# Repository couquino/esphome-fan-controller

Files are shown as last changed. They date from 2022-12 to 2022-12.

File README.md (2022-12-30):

# ESPHome Fan Controller
This repo gives you all the keys to build a quiet thermostat-controlled fan for cooling any enclosure (media console, DIY server cabinet...)

The software is ESPHome and works well with Home Assistant. For hardware, I used an ESP8266 and Artic BioniX F140 140mm fans.

This project is based on [ESPHome Fan Controller](https://github.com/patrickcollins12/esphome-fan-controller)

## What do I need ?
To build my DIY server cabinet thermostat-controlled fans, I used:
- ESP8266 (Any board should be compatible)
- LM2596 Buck Converter - to convert 12v down to 3.3v
- 12v Power Adapter and 12v DC Female Jack
- 12v PWM 4-pin Computer Fan - I picked some [BioniX F140](https://www.arctic.de/en/BioniX-F140/ACFAN00096A) from Arctic but you can use any 12V PWM-controllable fan
- DHT 11 temperature and humidity sensor

I also hired someone to design a custom PCB with 3 fan headers and slots for each component, you can find it in /pcb folder and order it on JLCPCB for example. (Thanks shazmeter for letting me share your work !)

⚠️ This is the V1 version of the PCB, there are some modifications to be made in order to be perfect !
The DC Barrel input does not fit the power supply I had, and the FAN1, FAN2 and FAN3 pins are not thick enough to secure the FANs cables. ⚠️

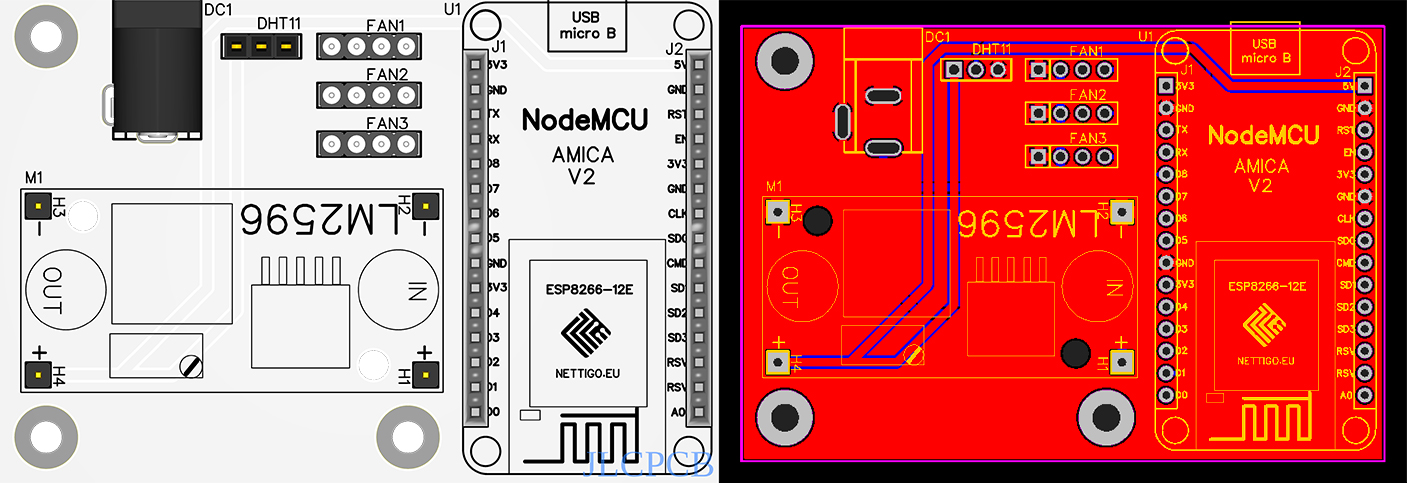
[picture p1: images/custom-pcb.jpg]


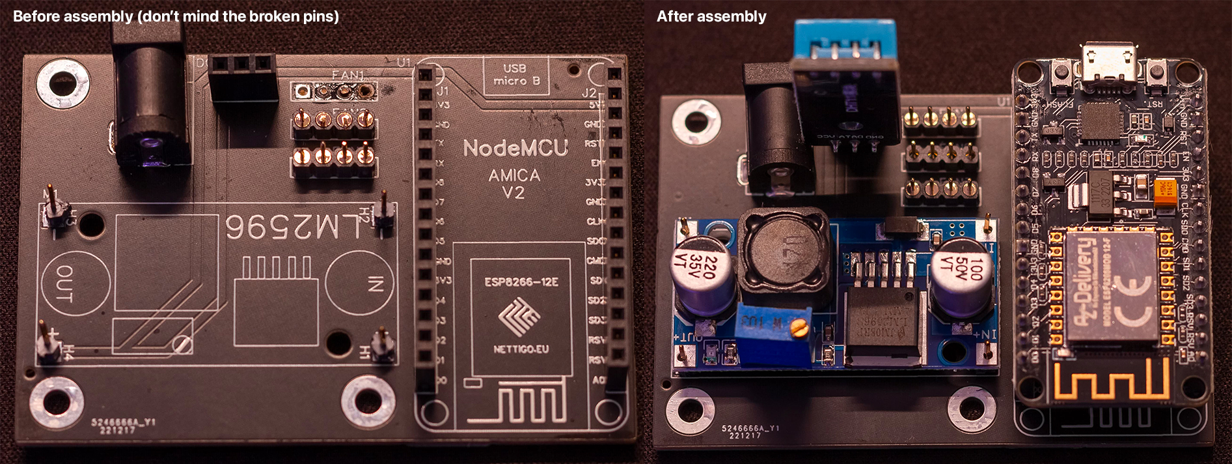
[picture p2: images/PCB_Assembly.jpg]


## Wiring Diagram
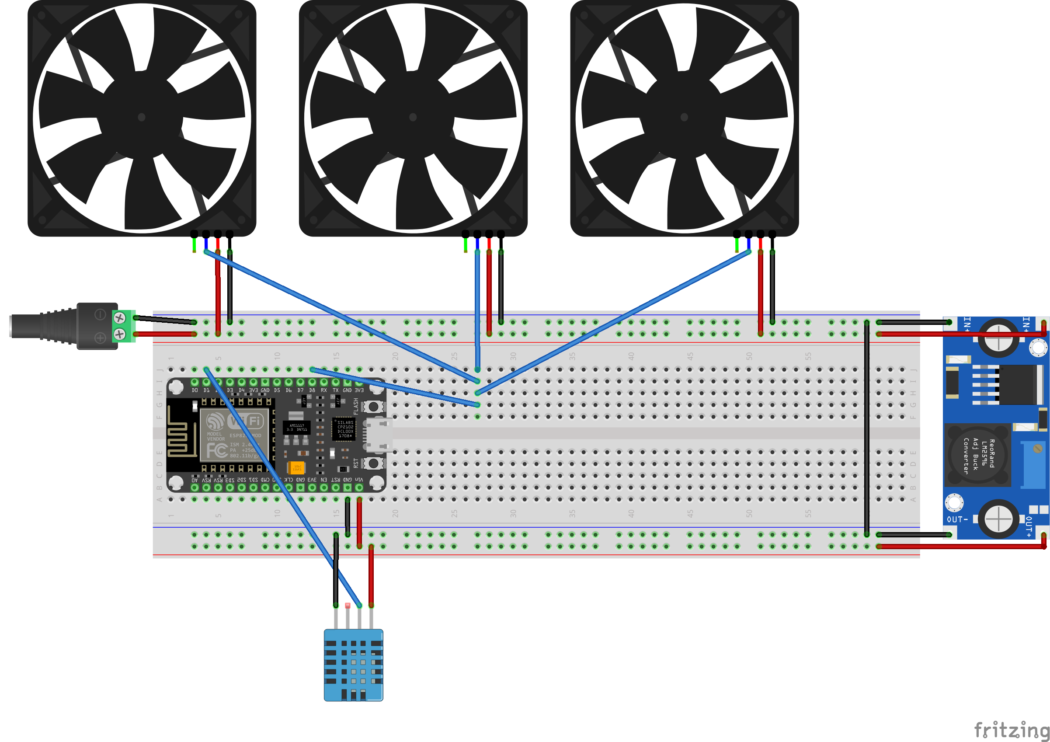
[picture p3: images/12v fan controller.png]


Some important notes:
- connect the fan PWM pin to a PWM GPIO
- turn the knob on the buck converter with a screwdriver to make it output exactly 3.3v. You'll need a multimeter to measure that output.
- ensure the 12v and 3.3v grounds are connected together.
- the unused pin on the fan is the "Tach" pin. This could tell you the RPM of the fan. We won't use this instead opting to measure the input voltage we're sending to the fan.
- you could easily skip the Buck converter and use two power sources 3.3v and 12v. 
- the fritzing diagram shows a 4-pin DHT-11, when in fact I have the simpler 3-pin version as shown in the parts list. The 4-pin version might need a pullup resistor, haven't tried it.

You can find the fritzing project in /fritzing-project folder

## Installing the software onto the ESP8266

### Get this repo
Clone this github repository.
From the command line cd into the directory

### Review the YAML and read the ESPHome docs.

Review the YAML file.

Ensure the pins are set correctly for the PWM Fan (D8) and the DHT-11 (D1).

Review the instructions for [the ESPHome Climate Thermostat](https://esphome.io/components/climate/index.html), [ESPHome PID Climate Thermostat](https://esphome.io/components/climate/pid.html) and the [DHT-11 sensor](https://esphome.io/components/sensor/dht.html).

Change the device name from ``console-fan`` to whatever seems appropriate. You might want to change the yaml filename as well.

Note that the DHT11 sensor is setup to average the last 15 readings. Each reading takes place every 1.5 seconds. Without this filter the PID controller reacts to every minor sensor movement. If you have a faster sensor like the BME260 you might need to tweak this filter.

```yaml
filters:
  - sliding_window_moving_average:
      window_size: 15
      send_every: 15
      send_first_at: 1
```

Also note that my fans have a max power of 80% applied to the fans to control the noise. You might want to remove this maximum.

```yaml
- platform: esp8266_pwm
    id: console_fan_speed
    pin: D8
    frequency: "25000 Hz" 
    min_power: 13%
    max_power: 80%
```

### Setup your wifi details

``mv secrets-sample.yaml secrets.yaml``

Edit your wifi credentials in secrets.yaml. The .gitignore will prevent you accidentally uploading your wifi credentials to github.

### Install ESPHome

[Install ESPHome](https://esphome.io/guides/installing_esphome.html) according to the instructions on the ESPHome website.

I prefer command-line on Mac:
``pip3 install esphome``

You could use the ESPHome that runs inside Home Assistant. 

### Install to ESP8266

Connect your ESP8266 via USB to your computer, then upload the Firmware to the ESP8266.

`` esphome run console-fan.yaml``

At this time if you've set the pins right, the sensor should be spitting out values and the PID can control the fan.

Success! 

```
% esphome logs console-fan.yaml
INFO Reading configuration console-fan.yaml...
INFO Starting log output from console-fan.local using esphome API
INFO Successfully connected to console-fan.local
...
[22:54:09][C][mdns:085]:   Hostname: console-fan
[22:54:09][C][homeassistant.text_sensor:023]: Homeassistant Text Sensor 'ha_kp'
[22:54:09][C][homeassistant.text_sensor:024]:   Entity ID: 'input_text.kp'
[22:54:10][C][homeassistant.text_sensor:023]: Homeassistant Text Sensor 'ha_ki'
[22:54:10][C][homeassistant.text_sensor:024]:   Entity ID: 'input_text.ki'
[22:54:10][C][homeassistant.text_sensor:023]: Homeassistant Text Sensor 'ha_kd'
[22:54:10][C][homeassistant.text_sensor:024]:   Entity ID: 'input_text.kd'
[22:54:10][D][dht:048]: Got Temperature=30.0°C Humidity=38.0%
[22:54:10][D][sensor:113]: 'Humidity': Sending state 38.00000 % with 0 decimals of accuracy
[22:54:11][D][dht:048]: Got Temperature=30.0°C Humidity=38.0%
[22:54:11][D][sensor:113]: 'Humidity': Sending state 38.00000 % with 0 decimals of accuracy
[22:54:12][D][dht:048]: Got Temperature=30.0°C Humidity=38.0%
[22:54:12][D][sensor:113]: 'Humidity': Sending state 38.00000 % with 0 decimals of accuracy
```

## Setup Home Assistant

If the above steps worked correctly, the device will be auto-discovered by Home Assistant. You will need to add the device.

Multiple sensors and switches are exposed by the ESPHome software.

You also need to setup the dashboard. I'll explain those two steps below.

## Setting up the Home Assistant Dashboard

dashboard

Here is my full dashboard in Home Assistant.

Let's go through them section by section.

### The Primary Controls



By clicking the thermostat you can turn on/off the thermostat and fan and adjust the target temperature which will be persisted to flash on the ESP8266.

```yaml
type: entities
title: Console Fan
entities:
  - entity: sensor.fan_speed_pwm_voltage
  - entity: climate.console_fan_thermostat
  - entity: sensor.contact_sensor_1_temperature
    name: Room Temperature
  - entity: sensor.openweathermap_temperature
    name: Outside temperature
  - entity: number.console_fan_kp
  - entity: number.console_fan_ki
  - entity: number.console_fan_kd
  ```

- The ``Fan Speed (PWM Voltage)`` is the % of voltage being sent out via PWM to the fan controller. At 100% it will be sending 12v, at 50% it will be sending 6v.

- The ``Console Fan Thermostat`` is a controllable thermostat, by clicking it you can alter the target temperature and turn the fan on/off.

- The Room and Outside temperatures are from other sensors in my house for reference.

- The ``kp, ki and kd`` inputs are exposed from the device. Your ESP8266 will be automatically receiving changes to these values to control the behavior of the PID controller. While you could tune these from the config.yaml it requires a compile, upload and reboot cycle each time. This is inconvenient and best to tweak in real-time. We want to expose these 3 parameters to a Home Assistant dashboard.

### The Graphs



Add the fan speed and the thermostat to two separate graphs. I've also added my room temperature from a separate device for comparison.

```yaml
type: vertical-stack
title: 3 hr
cards:
  - type: history-graph
    entities:
      - entity: sensor.fan_speed_pwm_voltage
    hours_to_show: 3
    refresh_interval: 0
  - type: history-graph
    entities:
      - entity: climate.console_fan_thermostat
        name: ' '
      - entity: sensor.contact_sensor_1_temperature
        name: room
    hours_to_show: 3
    refresh_interval: 0
```

### Helpful Details - More Sensors and Switches



This Lovelace YAML exposes various sensors and switches from the ESP8266.

```yaml
type: entities
entities:
  - entity: sensor.console_fan_ip_address
  - entity: sensor.console_fan_wifi_strength
  - entity: sensor.console_fan_uptime
  - entity: sensor.humidity
    name: console fan humidity
  - entity: switch.console_fan_autotune
  - entity: switch.console_fan_ESP8266_restart
```

- ``console_fan_autotune`` is a switch which starts the [PID tuning](https://esphome.io/components/climate/pid.html#autotuning) process. I ended up abandoning this approach and manually tuning the PID.

- ``console_fan_ESP8266_restart`` restarts the ESP8266 remotely.

## Configuring the PID Parameters

The thermostat is controlled using a standard Process Control system called a PID. 

In our system the goal of the PID control is to set the fan voltage (speed) to bring the temperature measured by the sensor to a target temperature (30degC).

Search the internet and you'll find many resources for setting up a PID Controller. There are a lot of resources for fast response systems like cruise control systems but not many for dealing with slow response cooling systems like this one.

The [ESPHome PID Climate](https://esphome.io/components/climate/pid.html) system that we're using here has some resources to explain how to tune the parameters. However, its autotune system didn't spit out useful results for me and I will explain how to manually get the right parameters. Your system will be different to mine and so your parameters will need to be slightly different. For instance, your cabinet will be a different size, I have two fans, you may only have one, etc.

There are only two parameters you will need to adjust: the kp and ki parameters. The kd parameter is not useful for us.

In my system the goal of tuning was to minimise aggressive changes to the fan (my wife complained she could hear the fan turning on and off). I don't mind the system drifting up to 2degC away from the target temporarily while it slowly reacts. A 7% drift (2degC/30degC) on some control systems could blow up a Nuclear plant or cause a Cruise Control system to crash into another car. But in our system a 7% short temperature drift is a fine tradeoff for quiet fans.

### Setting the kp (gain) parameter - how aggressively to cool?

KP is the main Gain. How aggressively will the fan respond to a small change in temperarature? Do you want the fan to go to 100% power in response to a 0.1degC change in temperature? In general my goal was to have the fan at 50% in response to a 1degC change in temperature, thus could normally stave off any further temperature rises, but if it the temperature did keep rising the fan will then climb to 100% power.

Using lower gain (0.1) (my preferred setting):
 - takes longer to cool down
 - is more likely to under react to fast temperature changes.
 - 2deg sharp spikes can occur before the system reacts
 - It can takes up to 10 minutes to fully close a 0.5degC gap.
 - but, it is much less likely to oscillate around the target temperature and cause the fan to turn on and off constantly.

Using higher gain (1.0):
 - responds quickly to changes in temperature
 - but, is more likely to oscillate and make the fan swing from 0% to 100% and back again as it tries to control the temperature. This means you can hear the fan trying to adjust.

### Setting the ki parameter - how long to adjust an offset?

``ki: 0.0009``

The ki parameter adjusts for temperature offset. Try setting ki to 0. Set your system initially with kp=0.1, ki=0 and kd=0. You'll find that the system operates with a constant delta/offset to the target temperature. The ki parameter adjusts for this.

1/ki is the seconds it should attempt to correct an offset. So 0.03 will adjust in 30seconds. 0.0009 will close a small temperature delta in 20 minutes. See a good description here https://blog.opticontrols.com/archives/344

Higher numbers like 0.03 will respond much quicker, but it also will cause a lot of noise and oscillation in the fan speed.

### Setting the kd parameter - predicting a change

The kd (D in PID) is meant to pre-react and backoff early. Small parameters can help overshoot but does create some fan noise and oscillation. The interwebs says that most (70%) of process controllers don't use the D and just a PI controller.

### Tell me
I'm keen to hear what PID parameters works for your fan.

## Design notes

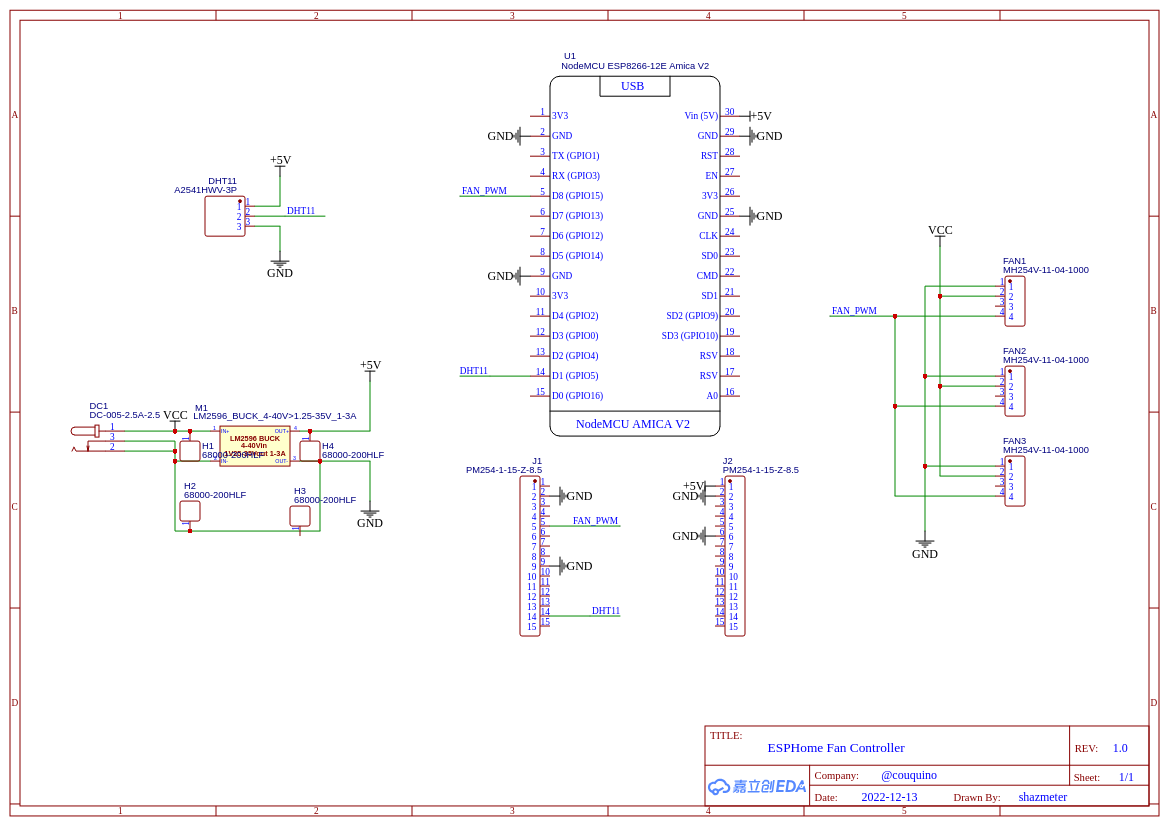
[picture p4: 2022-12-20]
images/custom-pcb-schema.png

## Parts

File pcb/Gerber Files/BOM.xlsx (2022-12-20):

Name | Designator | Footprint | Quantity | Manufacturer Part | Manufacturer | Supplier | Supplier Part | Price
DC-005-2.5A-2.5 | DC1 | CONN-TH_DC-005-2.5A-2.0 | 1 | DC-005-2.5A-2.5 | XKB Enterprise | LCSC | C319098 | 0.014
A2541HWV-3P | DHT11 | HDR-TH_3P-P2.54-V-F-1 | 1 | A2541HWV-3P | CJT(长江连接器) | LCSC | C225500 | 0.011
MH254V-11-04-1000 | FAN1,FAN2,FAN3 | HDR-TH_4P-P2.54-V-M-3 | 3 | MH254V-11-04-1000 | XFCN(兴飞) | LCSC | C509261 | 0.015
68000-200HLF | H1,H2,H3,H4 | HDR-TH_1P-P2.54-V-M | 4 | 68000-200HLF | Amphenol | LCSC | C213187 | 0.008
PM254-1-15-Z-8.5 | J1,J2 | HDR-TH_15P-P2.54-V-F | 2 | PM254-1-15-Z-8.5 | HCTL(华灿天禄) | LCSC | C2897378 | 0.036

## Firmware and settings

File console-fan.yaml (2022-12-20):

substitutions:
  friendly_name: Console Fan

esphome:
  name: console-fan

  # on_boot:
  #   priority: -100
  #   then: 
  #     lambda: |-
  #       // delay(10000);
  #       ESP_LOGI("main", "!!!!!! kp from boot %f", id("console_fan_kp") );
  #       id(console_thermostat).set_kp( id("$friendly_name kp") );

globals:
  - id: dhttemp
    type: float
    restore_value: yes
    initial_value: '0'
 
#########################
# ESP8266 AND NETWORK SETUP

esp8266:
  board: nodemcuv2

manual_ip:
  # Set this to the IP of the ESP
  static_ip: 192.168.1.XX
  # Set this to the IP address of the router. Often ends with .1
  gateway: 192.168.1.1
  # The subnet of the network. 255.255.255.0 works for most home networks.
  subnet: 255.255.255.0

# pid climate log update is noisy, dial it back to warn
logger:
  level: DEBUG
  logs: 
    climate: ERROR
    dht: WARN

# default HA integration, OTA updater and backup http web portal
api:
ota:
captive_portal:

wifi:

  # Read the wifi/pass from secrets.yaml:
  # wifi_ssid: "My Wifi XX"
  # wifi_password: "XXXXXXX"
  ssid: !secret wifi_ssid
  password: !secret wifi_password

  # Enable fallback hotspot (captive portal) in case wifi connection fails
  ap:
    ssid: "console-fan-ap"
    password: ""

number:

  ## RECEIVE kp,ki and kd parameters from input_text.kx helpers in 
  # Home Assistant. See the PID controller below
  # These helper values will get saved to flash thus permanently over-riding 
  # the initial values set in the PID below.

  # KP
  - platform: template
    name: $friendly_name kp
    icon: mdi:chart-bell-curve
    restore_value: true
    min_value: 0
    max_value: 50
    step: 0.001
    set_action: 
      lambda: |- 
        // ESP_LOGI("main", "!!!!!! kp from boot %d", id("console_fan_kp") );
        // id(console_thermostat).set_kp( id("$friendly_name kp") );
        id(console_thermostat).set_kp( x );

  # KI
  - platform: template
    name: $friendly_name ki
    icon: mdi:chart-bell-curve
    restore_value: true
    min_value: 0
    max_value: 50
    step: 0.0001
    set_action: 
      lambda: id(console_thermostat).set_ki( x );

  # KD
  - platform: template
    name: $friendly_name kd
    icon: mdi:chart-bell-curve
    restore_value: true
    min_value: -50
    max_value: 50
    step: 0.001
    set_action: 
      lambda: id(console_thermostat).set_kd( x );


text_sensor:

  # Send IP Address
  - platform: wifi_info
    ip_address:
      name: $friendly_name IP Address

  # Send Uptime in raw seconds
  - platform: template
    name: $friendly_name Uptime
    id: uptime_human
    icon: mdi:clock-start

sensor:

  # Send WiFi signal strength & uptime to HA
  - platform: wifi_signal
    name: $friendly_name WiFi Strength
    update_interval: 60s

  # This is a bit of overkill. It sends a human readable 
  # uptime string
  # 1h 41m 32s instead of 6092 seconds
  - platform: uptime
    name: $friendly_name Uptime
    id: uptime_sensor
    update_interval: 60s
    on_raw_value:
      then:
        - text_sensor.template.publish:
            id: uptime_human
            # Custom C++ code to generate the result
            state: !lambda |-
              int seconds = round(id(uptime_sensor).raw_state);
              int days = seconds / (24 * 3600);
              seconds = seconds % (24 * 3600);
              int hours = seconds / 3600;
              seconds = seconds % 3600;
              int minutes = seconds /  60;
              seconds = seconds % 60;
              return (
                (days ? to_string(days) + "d " : "") +
                (hours ? to_string(hours) + "h " : "") +
                (minutes ? to_string(minutes) + "m " : "") +
                (to_string(seconds) + "s")
              ).c_str();
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

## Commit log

2022-12-20 feat(pcb): added gerber files, bom and cpl for the PCB
    [BOM.xlsx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]
2022-12-20 feat(github): update readme
    [ESP Fan.fzz, breadboard.fzz]
2022-12-20 feat(pcb): move files, add project files for altium and easyeda
    [BOM.xlsx, PCB_ESPHome Fan.pcbdoc, SCH_ESPHome Fan.schdoc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]
2022-12-30 feat(github): add assembled pcb image
